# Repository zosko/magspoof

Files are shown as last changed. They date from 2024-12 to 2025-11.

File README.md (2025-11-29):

# Magspoof with Arduino Nano
Arduino magnetic card emulator track 1 and track 2

Components:
- L293D
- Arduino Nano
- COIL from 24awg wire, ~50 turns on 3cm diametar

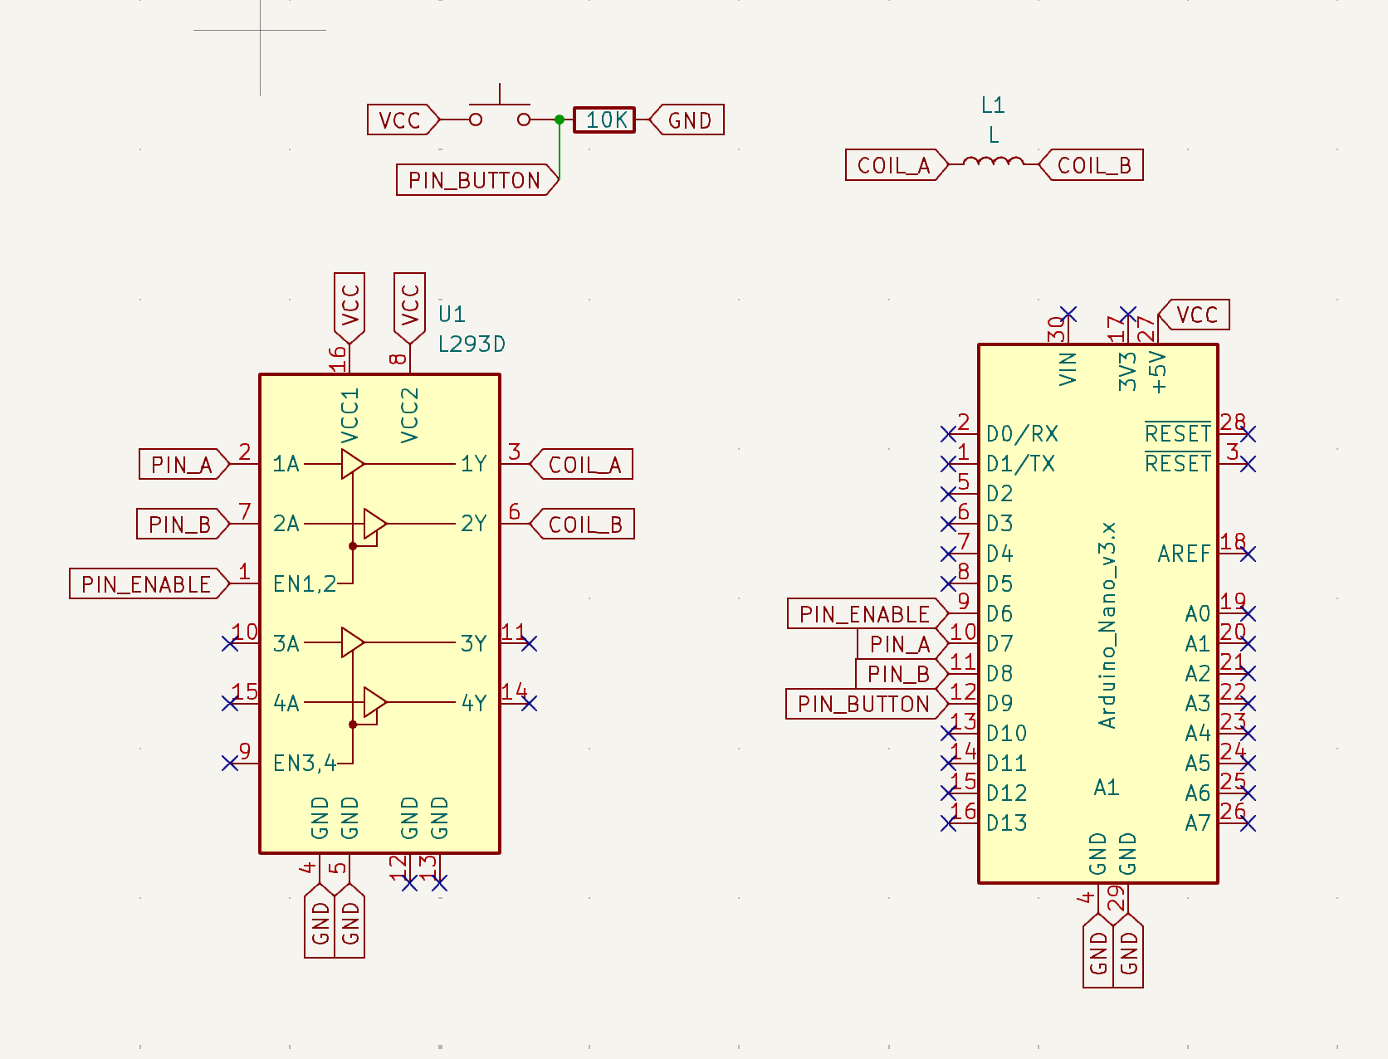
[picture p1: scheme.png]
scheme


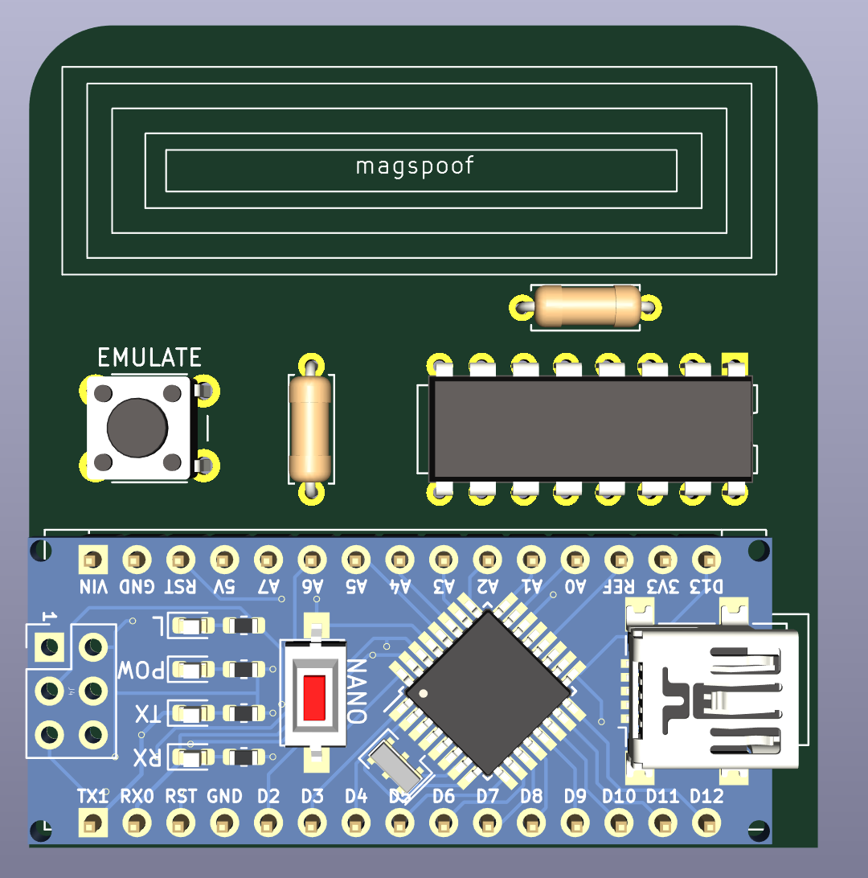
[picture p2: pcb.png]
pcb


Original: https://github.com/samyk/magspoof

## PCB Design

PCBWay_logo

**Huge thanks to [PCBWay](https://pcbway.com) for sponsoring this project!**

PCBWay is a leading provider of high-quality printed circuit boards (PCBs), offering reliable and affordable solutions for both hobbyists and professionals. Their services include rapid prototyping, PCB assembly, instant online quotations, expert design verification, and a streamlined ordering experience.

Their comprehensive range of services includes:
- PCB prototyping
- Assembly services
- Instant online quotations
- Expert design verification
- A streamlined, user-friendly ordering system

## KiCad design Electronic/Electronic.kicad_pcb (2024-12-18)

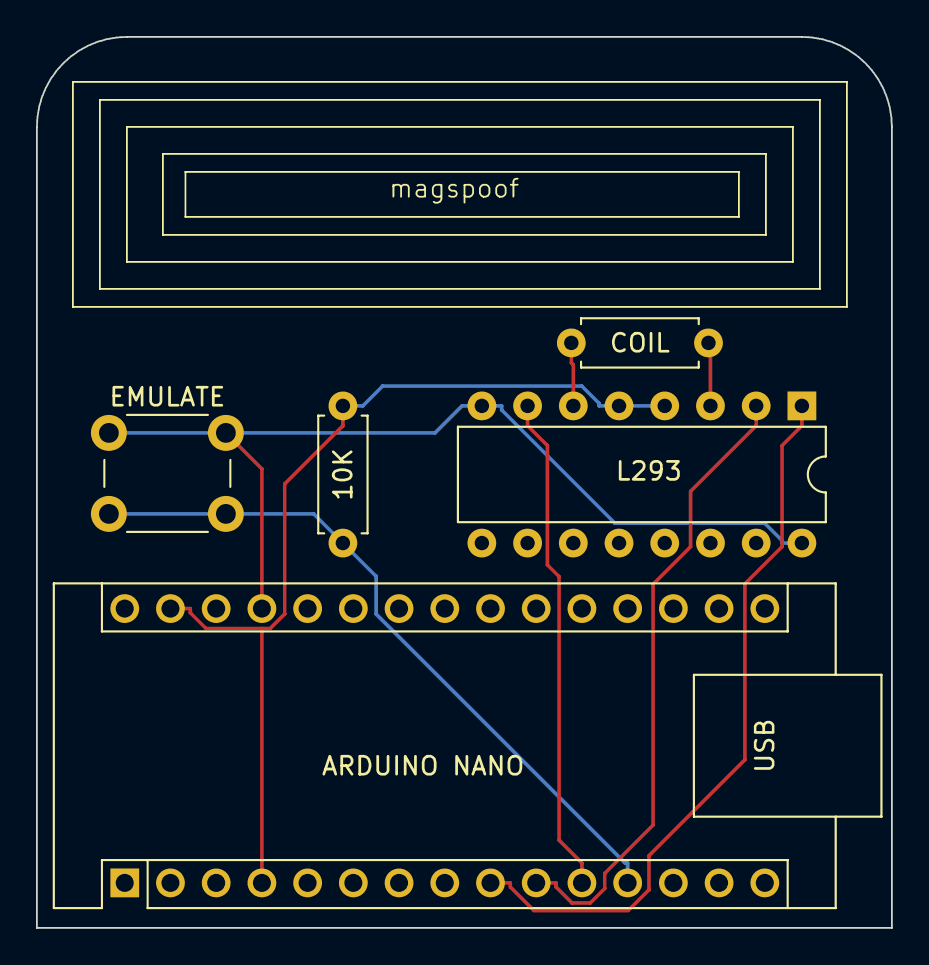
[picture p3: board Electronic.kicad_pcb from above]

Board: 2 copper layers, 47.5 x 49.5 mm, 5 parts (0 on the bottom side), 8 nets.

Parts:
10K: 10K; R_Axial_DIN0207_L6.3mm_D2.5mm_P7.62mm_Horizontal
ARDUINO NANO: Arduino_Nano_v3.x; Arduino_Nano
COIL: L; R_Axial_DIN0207_L6.3mm_D2.5mm_P7.62mm_Horizontal
EMULATE: SW_Push; SW_PUSH_6mm
L293: L293D; DIP-16_W7.62mm

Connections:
COIL_A: COIL.1, L293.3 (1Y)
COIL_B: COIL.2, L293.6 (2Y)
GND: 10K.2, ARDUINO NANO.4 (GND), ARDUINO NANO.29 (GND), L293.4 (GND), L293.5 (GND)
PIN_A: ARDUINO NANO.10 (D7), L293.2 (1A)
PIN_B: ARDUINO NANO.11 (D8), L293.7 (2A)
PIN_BUTTON: 10K.1, ARDUINO NANO.12 (D9), EMULATE.2
PIN_ENABLE: ARDUINO NANO.9 (D6), L293.1 (EN1,2)
VCC: ARDUINO NANO.27 (+5V), EMULATE.1, L293.8 (VCC2), L293.16 (VCC1)

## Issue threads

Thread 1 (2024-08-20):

did everything you did but not able to get anything from the card reader using the Arduino MagSpoof

jaekim24, 2024-08-20:
I cloned your repo and added my mag stripe info. When I emulate the card the card reader doesn't detect anything. Did you also have to issue at first?

zosko, 2024-09-17:
> I cloned your repo and added my mag stripe info. When I emulate the card the card reader doesn't detect anything. Did you also have to issue at first?

Are you using same setup that i have ? same arduino, components... etc ? if not you have to modify code.

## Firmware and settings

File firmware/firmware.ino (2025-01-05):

#define PIN_A 7
#define PIN_B 8
#define ENABLE_PIN 6
#define BUTTON_PIN 9
#define CLOCK_US 200

#define BETWEEN_ZERO 53 // 53 zeros between track1 & 2

// consts get stored in flash as we don't adjust them
const char* tracks[] = {
  "%B123456781234567^LASTNAME/FIRST^YYMMSSSDDDDDDDDDDDDDDDDDDDDDDDDD?\0", // Track 1
  ";123456781234567=YYMMSSSDDDDDDDDDDDDDD?\0" // Track 2
};

char revTrack[41];

const int sublen[] = { 32, 48, 48 };
const int bitlen[] = { 7, 5, 5 };

unsigned int curTrack = 0;
int dir;

// send a single bit out
void playBit(int sendBit) {
  dir ^= 1;
  digitalWrite(PIN_A, dir);
  digitalWrite(PIN_B, !dir);
  delayMicroseconds(CLOCK_US);

  if (sendBit) {
    dir ^= 1;
    digitalWrite(PIN_A, dir);
    digitalWrite(PIN_B, !dir);
  }
  delayMicroseconds(CLOCK_US);
}

// when reversing
void reverseTrack(int track) {
  int i = 0;
  track--; // index 0
  dir = 0;

  while (revTrack[i++] != '\0');
  i--;
  while (i--)
    for (int j = bitlen[track] - 1; j >= 0; j--)
      playBit((revTrack[i] >> j) & 1);
}

// plays out a full track, calculating CRCs and LRC
void playTrack(int track) {
  int tmp = 0;
  int crc = 0;
  int lrc = 0;
  track--; // index 0
  dir = 0;

  // enable H-bridge and LED
  digitalWrite(ENABLE_PIN, HIGH);

  // First put out a bunch of leading zeros.
  for (int i = 0; i < 25; i++)
    playBit(0);

  //
  for (int i = 0; tracks[track][i] != '\0'; i++) {
    crc = 1;
    tmp = tracks[track][i] - sublen[track];

    for (int j = 0; j < bitlen[track] - 1; j++) {
      crc ^= tmp & 1;
      lrc ^= (tmp & 1) << j;
      playBit(tmp & 1);
      tmp >>= 1;
    }
    playBit(crc);
  }

  // finish calculating and send last "byte" (LRC)
  tmp = lrc;
  crc = 1;
  for (int j = 0; j < bitlen[track] - 1; j++) {
    crc ^= tmp & 1;
    playBit(tmp & 1);
    tmp >>= 1;
  }
  playBit(crc);

  // if track 1, play 2nd track in reverse (like swiping back?)
  if (track == 0) {
    // if track 1, also play track 2 in reverse
    // zeros in between
    for (int i = 0; i < BETWEEN_ZERO; i++)
      playBit(0);

    // send second track in reverse
    reverseTrack(2);
  }

  // finish with 0's
  for (int i = 0; i < 25; i++)
    playBit(0);

  digitalWrite(PIN_A, LOW);
  digitalWrite(PIN_B, LOW);
  digitalWrite(ENABLE_PIN, LOW);
}

// stores track for reverse usage later
void storeRevTrack(int track) {
  int i = 0;
  int tmp = 0;
  int crc = 0;
  int lrc = 0;

  track--; // index 0
  dir = 0;

  for (i = 0; tracks[track][i] != '\0'; i++) {
    crc = 1;
    tmp = tracks[track][i] - sublen[track];

    for (int j = 0; j < bitlen[track] - 1; j++) {
      crc ^= tmp & 1;
      lrc ^= (tmp & 1) << j;
      tmp & 1 ? (revTrack[i] |= 1 << j) : (revTrack[i] &= ~(1 << j));
      tmp >>= 1;
    }
    crc ? (revTrack[i] |= 1 << 4) : (revTrack[i] &= ~(1 << 4));
  }

  // finish calculating and send last "byte" (LRC)
  tmp = lrc;
  crc = 1;
  for (int j = 0; j < bitlen[track] - 1; j++) {
    crc ^= tmp & 1;
    tmp & 1 ? (revTrack[i] |= 1 << j) : (revTrack[i] &= ~(1 << j));
    tmp >>= 1;
  }
  crc ? (revTrack[i] |= 1 << 4) : (revTrack[i] &= ~(1 << 4));

  i++;
  revTrack[i] = '\0';
}

void setup() {
  Serial.begin(9600);
  
  pinMode(LED_BUILTIN, OUTPUT);
  pinMode(PIN_A, OUTPUT);
  pinMode(PIN_B, OUTPUT);
  pinMode(ENABLE_PIN, OUTPUT);
  pinMode(BUTTON_PIN, INPUT);

  // store reverse track 2 to play later
  storeRevTrack(2);
}
void loop() {
  while (digitalRead(BUTTON_PIN) == HIGH) {
    Serial.println("EMULATE CARD");
    digitalWrite(LED_BUILTIN,HIGH);
    playTrack(1 + (curTrack++ % 2));
    delay(1000);
  }
  digitalWrite(LED_BUILTIN, LOW);
}
